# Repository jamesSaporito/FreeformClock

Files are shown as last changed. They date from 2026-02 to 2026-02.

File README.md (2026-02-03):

# Freeform Clock

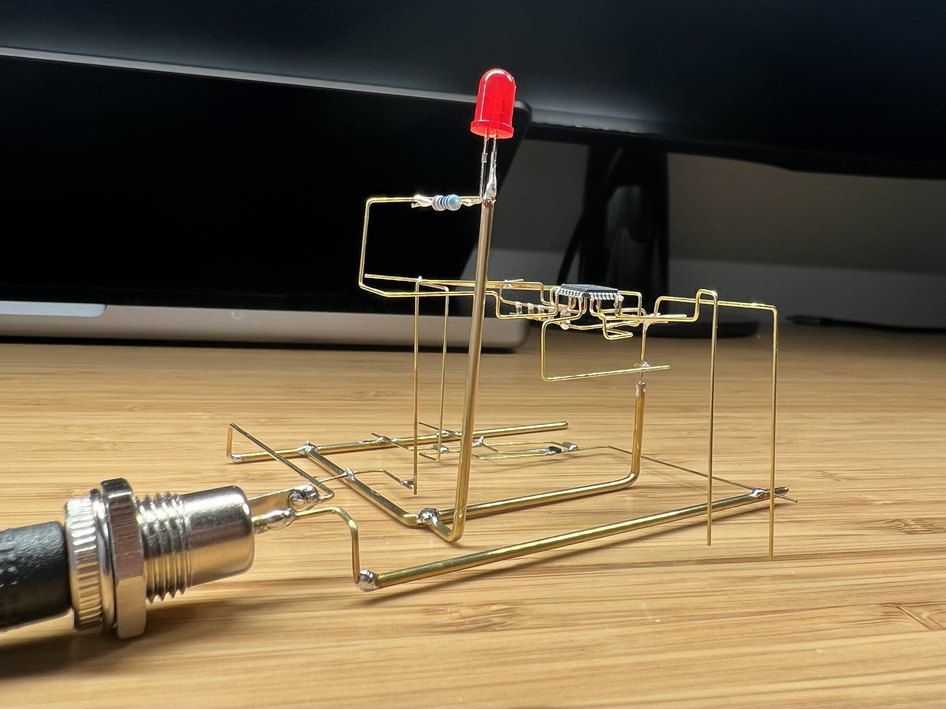
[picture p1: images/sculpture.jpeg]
Freeform clock


This project was both an experiement and exercise in making something with parts I already had.
It uses an STM32 and one red LED that tells the time in morse code.

Even though it works as intended, it's not at all reliable as a clock. Due to the time consumption of
soldering everything in awkward positions, I skipped adding an external 32.768kHz crystal that would
ensure the RTC is accurate. During testing, I observed the duration of "one minute" is roughly 50 seconds.

The inspriation for this came from examples of freeform circuits that intrigued me, specifically the
works of [Eirik Brandal](https://eirikbrandal.com/) and [Mohit Bhoite](https://bhoite.com/).

This is the first one I've made, so it's a bit rough.

# Setting Time

The only method to set the time is to plug the clock in at midnight. When powered on, the RTC starts at `00:00` in 24 hour time format. There is no way to set the time once plugged in.

# Programming   

It is programmable via SWD and some alligator clips. I positioned several rods far out enough to be
able to carefully connect to and program the STM32. While this does work, it's quite delicate and very
easy to accidentially bend a rod out of place. Best not to do this often.

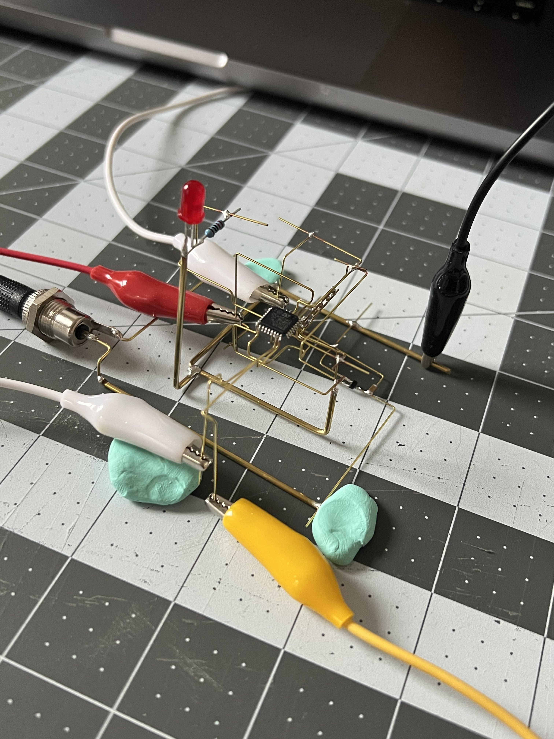
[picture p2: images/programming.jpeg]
Programming the clock


# Core Components

* [STM32](https://www.st.com/resource/en/datasheet/stm32l010f4.pdf)
* [3.3V voltage regulator](https://www.ti.com/lit/ds/symlink/tps7a05.pdf).
* DC Jack
* All necessary decoupling capacitors/etc that would be used in a practical PCB.
* Red LED
* 5V DC power supply (center positive) 

Everything is soldered together using K & S Precision Metals brass rods. A few different sizes were used.
The smallest size used was [0.51mm](https://ksmetals.com/products/brrmet-h), which was for soldering
directly to the pins of the STM32, as well as other small components. [0.81mm](https://ksmetals.com/products/brr-1-32) and [1.5mm](https://ksmetals.com/products/br225mm-1h) were used for power and ground rails, as well
as a rigid structure.

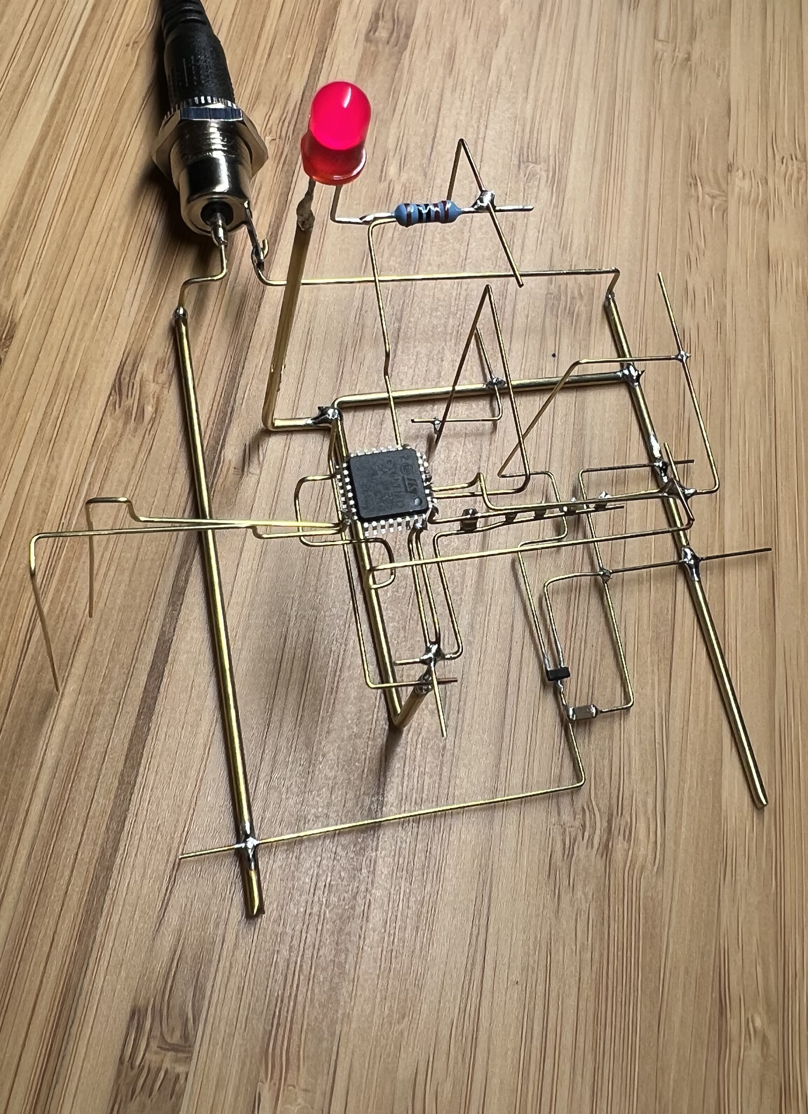
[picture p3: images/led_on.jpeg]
LED on


The very first thing you'll see ~1 minute after powering the clock, which translates to 12:01 a.m.

Displaying 00:01

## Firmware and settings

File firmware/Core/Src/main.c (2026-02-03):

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
/* Includes ------------------------------------------------------------------*/
#include "main.h"

/* USER CODE BEGIN PD */

/*
 * Used to split bytes into an array. Allows us to display one digit at a time.
 */
#define HI_NIBBLE(byte) (((byte) >> 4) & 0x0F)
#define LO_NIBBLE(byte) ((byte) & 0x0F)

/* USER CODE END PD */

RTC_HandleTypeDef hrtc;

/* USER CODE BEGIN PV */

/**
 * There's no real standard for the dit length, and it's not common to define it
 * arbitrarily. Instead, words per minute is used based on an "average" word of five
 * characters. PARIS is a common choice. This matters because each letter can result
 * in a difference in the total elements sent.
 * 
 * Analyzing PARIS:
 * 
 * Dit                     = .
 * Dah                     = -
 * Off time                = _
 * Character space (SPACE) = ...     (3 dits)
 * Word space      (END)   = ....... (7 dits)
 * 
 * P = .--.
 * A = .-
 * R = .-.
 * I = ..
 * S = ...
 * 
 * Then add the spacing per character/word
 * 
 * P     .--.
 * SPACE ...
 * A     .-
 * SPACE ...
 * R     .-.
 * SPACE ...
 * I     ..
 * SPACE ...
 * S     ...
 * END   .......
 * 
 * Finally, add the off time between dits and dahs.
 * 
 * P     ._-_-_.
 * SPACE ...
 * A     ._-
 * SPACE ...
 * R     ._-_.
 * SPACE ...
 * I     ._.
 * SPACE ...
 * S     ._._.
 * END   .......
 * 
 * This gives us a total of 50 dits.
 * 
 * Dits = 50
 * 60 seconds = 60000 milliseconds
 * X = One minute(ms)/Total dits
 * X = 60000/50 = 1200
 * Dit Length = X/WPM
 * Dit Length = 1200/20
 * Dit Length = 60ms
 */
const int ditLength = 60;
const int dahLength = ditLength * 3;
const int characterSpace = 3;
const int wordSpace = 7;

/**
 * Flag that is set in the interrupt callback, which starts the display logic
 * for the current time.
 */
int displayTime = 0;

/**
 * Dit = 0
 * Dah = 1
 */
int morseNumbers[10][5] = {
	{1,1,1,1,1}, // 0
	{0,1,1,1,1}, // 1
	{0,0,1,1,1}, // 2
	{0,0,0,1,1}, // 3
	{0,0,0,0,1}, // 4
	{0,0,0,0,0}, // 5
	{1,0,0,0,0}, // 6
	{1,1,0,0,0}, // 7
	{1,1,1,0,0}, // 8
	{1,1,1,1,0}, // 9
};

/* USER CODE END PV */

void SystemClock_Config(void);
static void MX_GPIO_Init(void);
static void MX_RTC_Init(void);
/**
  * @brief  The application entry point.
  * @retval int
  */
int main(void)
{

  /* MCU Configuration--------------------------------------------------------*/

  /* Reset of all peripherals, Initializes the Flash interface and the Systick. */
  HAL_Init();

  /* Configure the system clock */
  SystemClock_Config();

  /* Initialize all configured peripherals */
  MX_GPIO_Init();
  MX_RTC_Init();
  /* USER CODE BEGIN 2 */

	RTC_TimeTypeDef time;
	RTC_DateTypeDef date;
	uint8_t currentTime[4];

  /* USER CODE END 2 */

  /* Infinite loop */
  /* USER CODE BEGIN WHILE */
  while (1)
  {
    /* USER CODE END WHILE */

    if (displayTime == 1) {
      HAL_RTC_GetTime(&hrtc, &time, RTC_FORMAT_BCD);
		  HAL_RTC_GetDate(&hrtc, &date, RTC_FORMAT_BCD);

      currentTime[0] = HI_NIBBLE(time.Hours);
      currentTime[1] = LO_NIBBLE(time.Hours);
      currentTime[2] = HI_NIBBLE(time.Minutes);
      currentTime[3] = LO_NIBBLE(time.Minutes);

      for (int i = 0; i < sizeof(currentTime); i++) {
			  int *currentNumber = morseNumbers[currentTime[i]];
        for (int j = 0; j <= sizeof(currentNumber); j++) {
          HAL_GPIO_WritePin(GPIOA, GPIO_PIN_3, GPIO_PIN_SET);
          
          // Delay the desired amount of time based on a dit or dah.
          if (currentNumber[j] == 0) {
            HAL_Delay(ditLength);
          } else {
            HAL_Delay(dahLength);
          }

          HAL_GPIO_WritePin(GPIOA, GPIO_PIN_3, GPIO_PIN_RESET);
          
          // Space for end of the "word" (number in this case).
          HAL_Delay(ditLength * characterSpace);
        }
      }
      displayTime = 0;
    }
    /* USER CODE BEGIN 3 */
  }
  /* USER CODE END 3 */
}

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
/* USER CODE BEGIN 4 */

/**
 * Set the flag to execute the display logic in the main loop.
 */
void HAL_RTC_AlarmAEventCallback(RTC_HandleTypeDef *hrtc)
{
	displayTime = 1;
}

/* USER CODE END 4 */
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


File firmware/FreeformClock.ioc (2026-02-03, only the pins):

Mcu.UserName=STM32L010K4Tx
PA13.Signal=SYS_SWDIO
PA14.Signal=SYS_SWCLK
PA3.Signal=GPIO_Output

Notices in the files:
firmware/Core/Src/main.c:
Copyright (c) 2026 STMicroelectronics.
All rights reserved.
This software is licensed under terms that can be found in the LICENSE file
